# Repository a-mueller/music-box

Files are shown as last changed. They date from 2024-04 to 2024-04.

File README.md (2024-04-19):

# Music Box

A rfid based player I made. It basically scans for RFID takes, and looks for a WAV file on the SD card with that ID, if found it plays it.
The WAV files need to be 22khz, 16bit mono. Audacity is a good tool to convert mp3s.

## Board

The board is simply a pico with and SD card and the I2S chip.

See KiCad files.

### Schematic

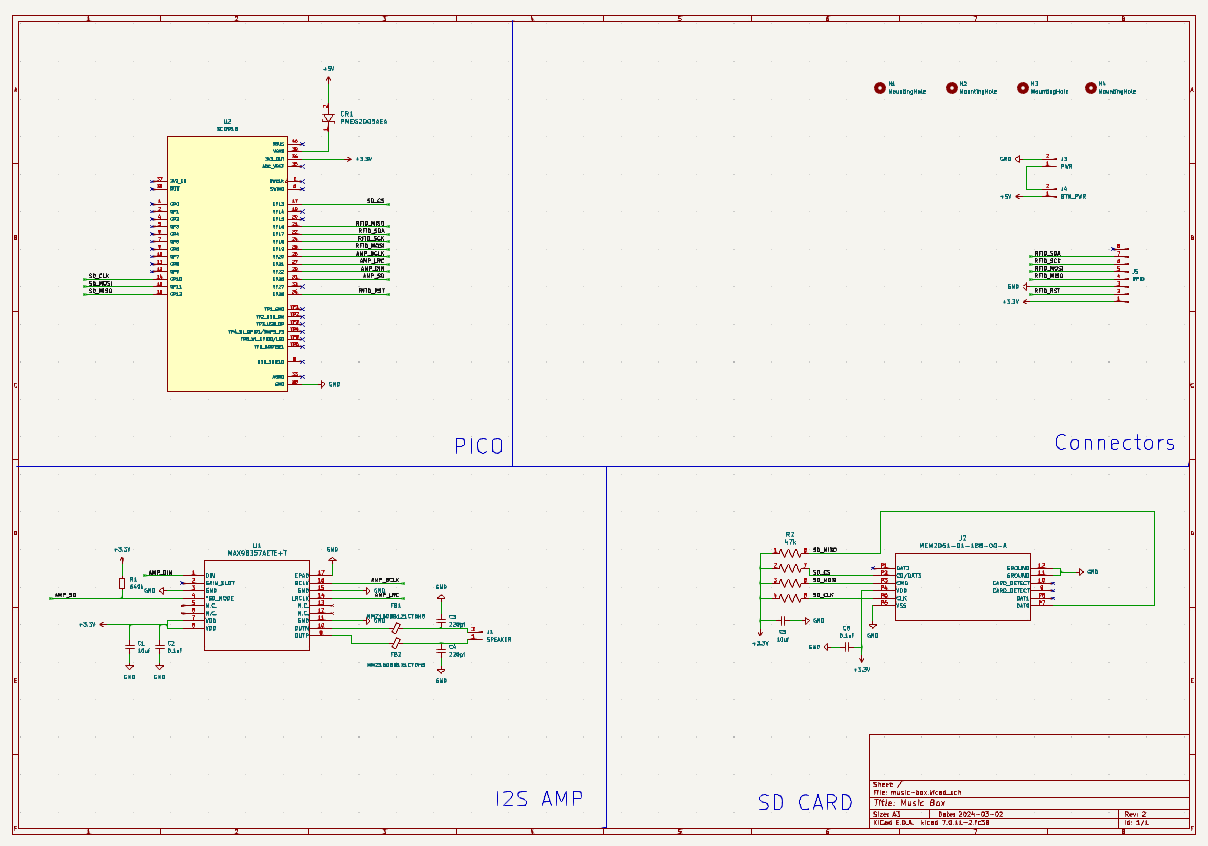
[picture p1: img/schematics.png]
Schematic


### PCB

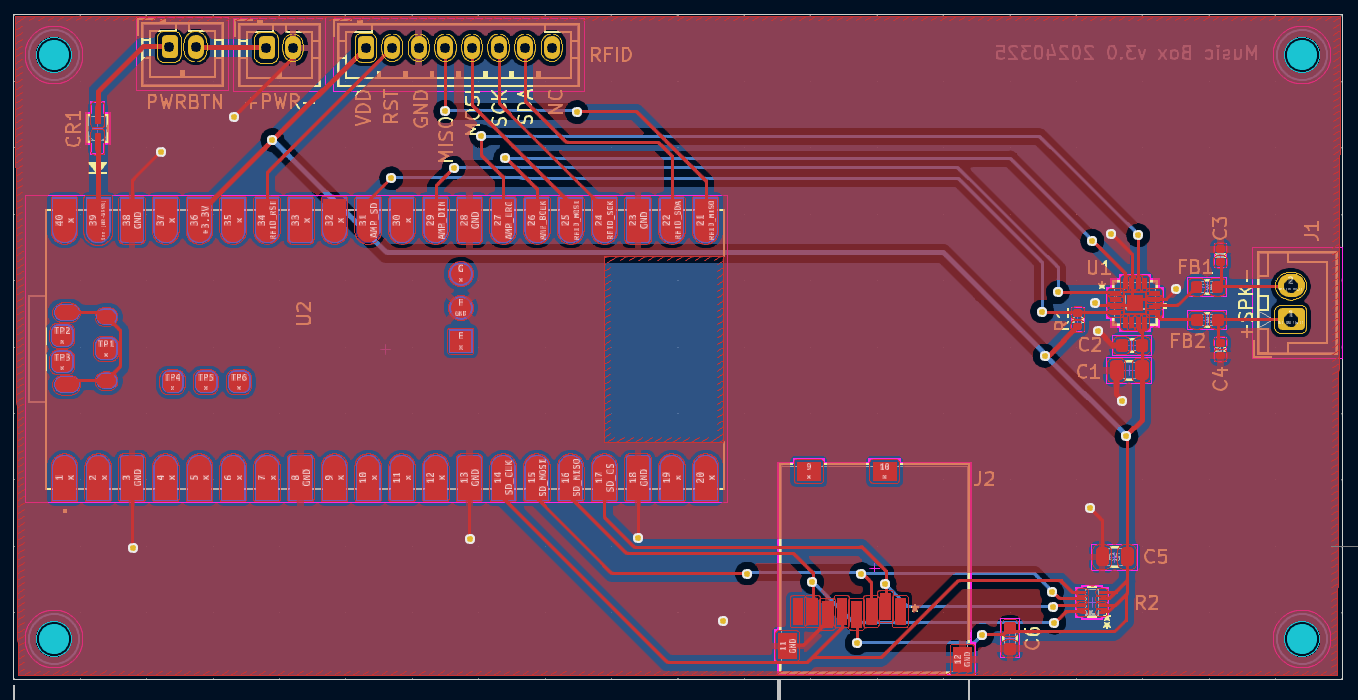
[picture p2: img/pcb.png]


### BOM

<table>
<tr><td>CR1</td><td>PMEG2005AEA</td><td>https://uk.farnell.com/nexperia/pmeg2005aea-115/diode-schottky-sod-323/dp/8737843?st=pmeg2005aea</td></tr>
<tr><td>J2</td><td>GCT MEM2061-01-188-00-A</td><td>https://uk.farnell.com/gct-global-connector-technology/mem2061-01-188-00-a/micro-sd-conn-push-push-8pos-smt/dp/2678544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</td></tr>
<tr><td>C6, C2</td><td>0.1uf, 0603</td><td></td></tr>
<tr><td>C5, C1</td><td>10uf, 0805</td><td></td></tr>
<tr><td>R2</td><td>Array, 4x 47k (EXB-N8V473JX)</td><td>https://uk.farnell.com/panasonic/exbn8v473jx/resistor-ccav-array-0402x4-47k/dp/2060146?st=EXBN8V473JX</td></tr>
<tr><td>R6</td><td>649k, 0402</td><td></td></tr>
<tr><td>U1</td><td>I2S Amp, MAX98357AETE+T</td><td>https://uk.farnell.com/analog-devices/max98357aete-t/audio-power-amp-d-40-to-85deg/dp/2949165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</td></tr>
<tr><td>FB1, FB2</td><td>Ferrite Beads, MMZ1608B121CTDH5</td><td>https://uk.farnell.com/tdk/mmz1608b121ctdh5/ferrite-chip-bead-1608-0-15-ohm/dp/3386884?st=mmz1608b121ctdh5</td></tr>
<tr><td>C4,C3</td><td>220pf, 0402</td><td></td></tr>
<tr><td>J1</td><td>JST, XH 2.5mm</td><td></td></tr>
<tr><td>J4, J3, J5</td><td>JST, PH, 2mm</td><td></td></tr>

</table>

## Software

Flash circuit python (originally I used v9) and copy the lib folder and `code.py` files over. That should be it.

## Case

See FreeCad files in `3dPrinting`, you will need a usbc power board as well to power it (see https://github.com/a-mueller/usbc_power_supply_2)

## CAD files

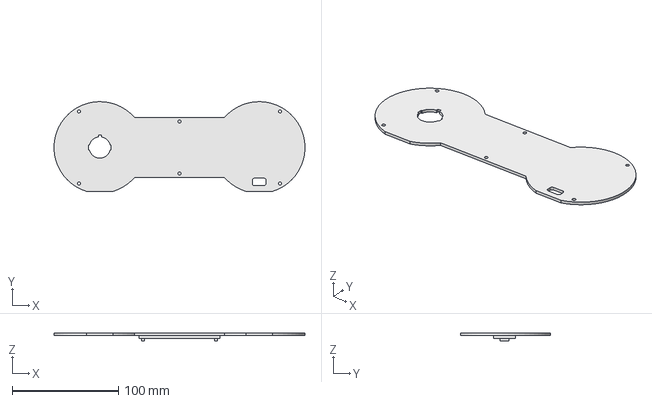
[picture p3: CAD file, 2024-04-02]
3dPrinting/music-box-2.FCStd
236.2 x 84.5 x 7.90 mm

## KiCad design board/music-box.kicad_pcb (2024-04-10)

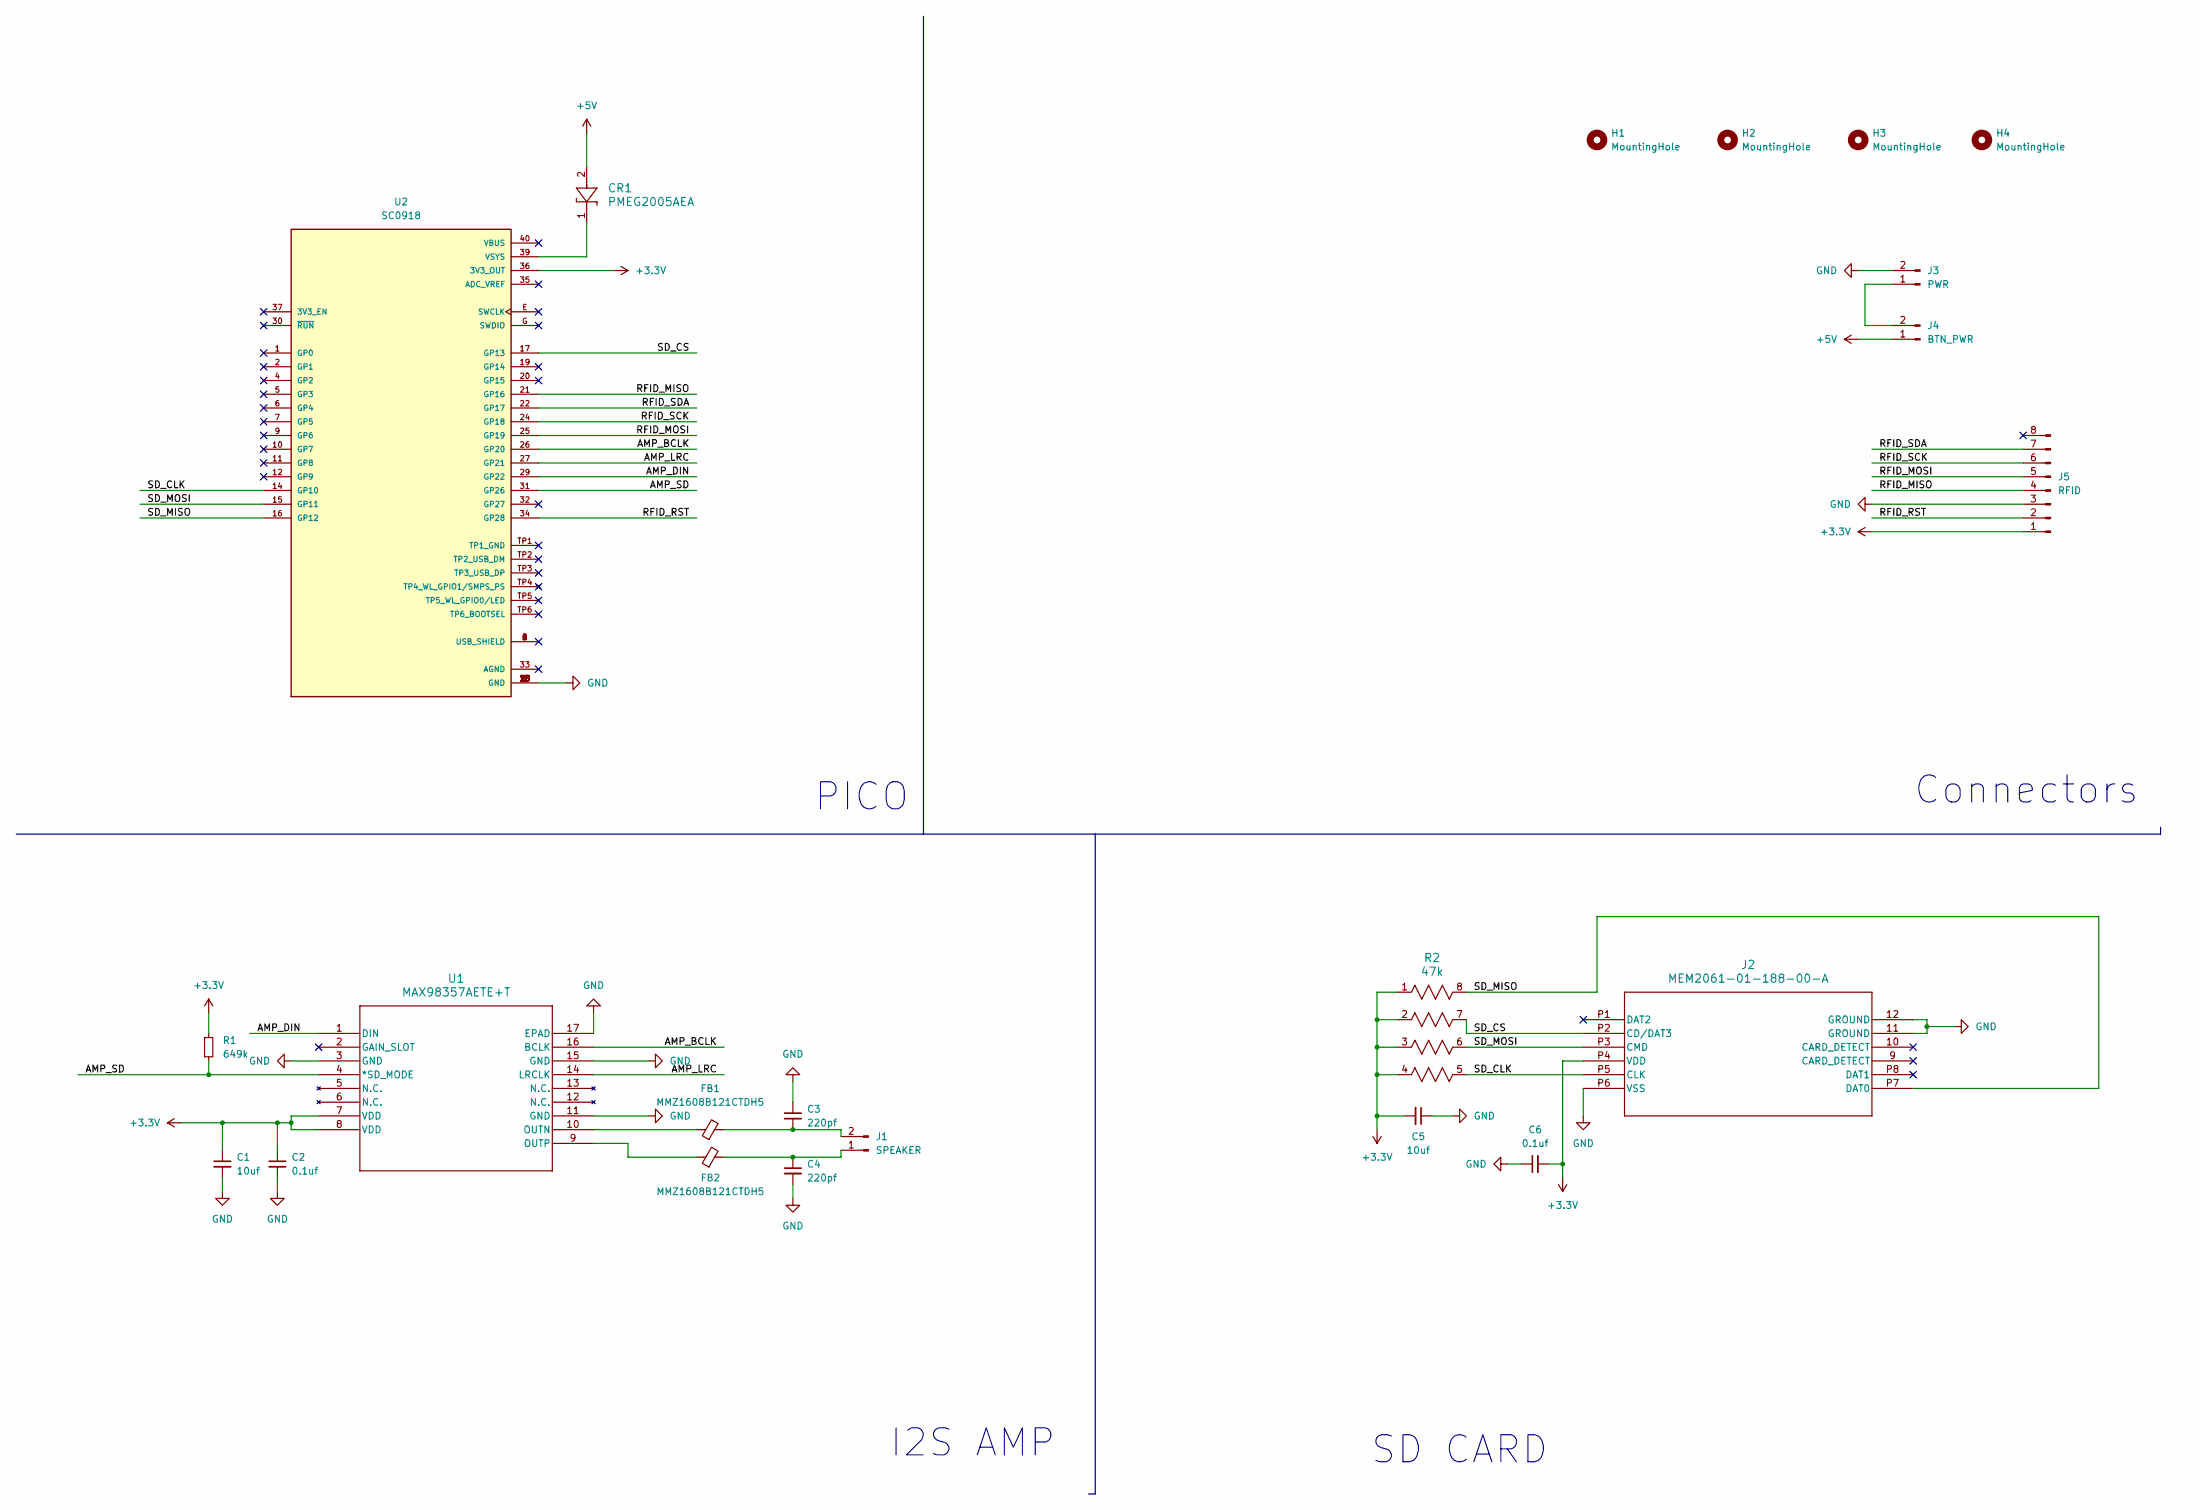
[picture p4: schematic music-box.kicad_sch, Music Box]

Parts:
C1, C5: 10uf; C_0805_2012Metric
C2, C6: 0.1uf; C_0603_1608Metric
C3, C4: 220pf; C_0402_1005Metric
CR1: PMEG2005AEA; SOD323F_NEX
FB1, FB2: MMZ1608B121CTDH5; L_0603_1608Metric
H1, H2, H3, H4: MountingHole; MountingHole_2.2mm_M2_DIN965
J1: SPEAKER; JST_XH_B2B-XH-A_1x02_P2.50mm_Vertical
J2: MEM2061-01-188-00-A; MEM2061-01-188-00-A_GCT
J3: PWR; JST_PH_B2B-PH-K_1x02_P2.00mm_Vertical
J4: BTN_PWR; JST_PH_B2B-PH-K_1x02_P2.00mm_Vertical
J5: RFID; JST_PH_B8B-PH-K_1x08_P2.00mm_Vertical
R1: 649k; R_0402_1005Metric
R2: 47k; EXBN8V_PAN
U1: MAX98357AETE+T; 21-0136I_T1633-4_MXM
U2: SC0918; MODULE_SC0918; PARTREV 2.1

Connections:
+3.3V: C1.1, C2.1, C5.2, C6.2, J2.P4 (VDD), J5.1, R1.1, R2.1, R2.2, R2.3, R2.4, U1.7 (VDD), U1.8 (VDD), U2.36 (3V3_OUT)
+5V: CR1.2, J4.1
/AMP_BCLK: U1.16 (BCLK), U2.26 (GP20)
/AMP_DIN: U1.1 (DIN), U2.29 (GP22)
/AMP_LRC: U1.14 (LRCLK), U2.27 (GP21)
/AMP_SD: R1.2, U1.4 (*SD_MODE), U2.31 (GP26)
/RFID_MISO: J5.4, U2.21 (GP16)
/RFID_MOSI: J5.5, U2.25 (GP19)
/RFID_RST: J5.2, U2.34 (GP28)
/RFID_SCK: J5.6, U2.24 (GP18)
/RFID_SDA: J5.7, U2.22 (GP17)
/SD_CLK: J2.P5 (CLK), R2.5, U2.14 (GP10)
/SD_CS: J2.P2 (CD/DAT3), R2.7, U2.17 (GP13)
/SD_MISO: J2.P7 (DAT0), R2.8, U2.16 (GP12)
/SD_MOSI: J2.P3 (CMD), R2.6, U2.15 (GP11)
GND: C1.2, C2.2, C3.1, C4.2, C5.1, C6.1, J2.11 (GROUND), J2.12 (GROUND), J2.P6 (VSS), J3.2, J5.3, U1.3 (GND), U1.11 (GND), U1.15 (GND), U1.17 (EPAD), U2.3 (GND), U2.8 (GND), U2.13 (GND), U2.18 (GND), U2.23 (GND), U2.28 (GND), U2.38 (GND), U2.F (GND)
unnamed: C4.1, FB2.2, J1.1
unnamed: C3.2, FB1.2, J1.2
unnamed: J3.1, J4.2
unnamed: FB1.1, U1.10 (OUTN)
unnamed: FB2.1, U1.9 (OUTP)
unnamed: CR1.1, U2.39 (VSYS)

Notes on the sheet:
Connectors
I2S AMP
PICO
SD CARD

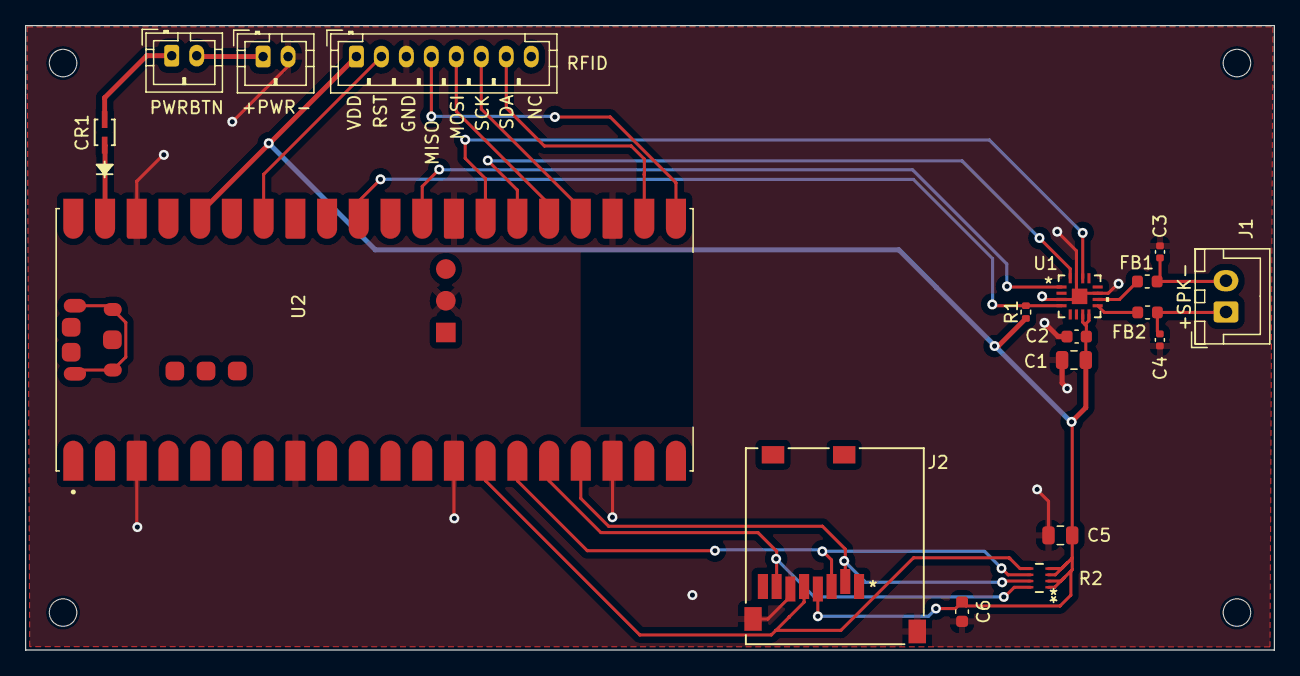
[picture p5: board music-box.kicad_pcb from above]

Board: 2 copper layers, 100.0 x 50.0 mm, 22 parts (0 on the bottom side), 22 nets.

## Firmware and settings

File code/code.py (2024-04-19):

import time
import array
import math
import audiocore
import board
import audiobusio
import busio
import digitalio
import storage
import adafruit_sdcard
import mfrc522
import alarm
import os

print("Running music box")

# SPI for the SD card
spi_sd = busio.SPI(clock = board.GP10, MOSI = board.GP11, MISO = board.GP12) #clock, mosi, miso
# Select pin for the SD card
sd_select = digitalio.DigitalInOut(board.GP13)
# SD card lib
sdcard = adafruit_sdcard.SDCard(spi_sd, sd_select)

while True:
  try:
    # mount the sd card to /sd
    vfs = storage.VfsFat(sdcard)
    storage.mount(vfs, "/sd")
    break
  except:
    print("Error mounting SD card")
    time.sleep(1)

# RFID card reader
spi_rfid = busio.SPI(board.GP18, board.GP19, board.GP16) #clock, mosi, miso
rfid = mfrc522.MFRC522(spi_rfid, board.GP28, board.GP17)


# I2S audio output & amp
amp_power = digitalio.DigitalInOut(board.GP26)
amp_power.switch_to_output()
audio = audiobusio.I2SOut(bit_clock=board.GP20, word_select=board.GP21, data=board.GP22)

# Make sure the amp is powered
amp_power.value = True


while True:
  (status, tag_type) = rfid.request(rfid.REQIDL)
  if status == rfid.OK:
    (stat, raw_uid) = rfid.anticoll()
    if (stat == rfid.OK):
      uid = "0x" + "%02x%02x%02x%02x" % (raw_uid[0], raw_uid[1], raw_uid[2], raw_uid[3])
      path = "/sd/" + "%02x%02x%02x%02x.wav" % (raw_uid[0], raw_uid[1], raw_uid[2], raw_uid[3])
      try:
        os.stat(path)
      except:
        path = "/unknown_card.wav"

      print("Playing path: "+path)

      with open(path, "rb") as wave_file:
        wave = audiocore.WaveFile(wave_file)
        audio.play(wave)
        while (audio.playing and stat == rfid.OK):
          time.sleep(0.5)
          (stat, raw_uid) = rfid.anticoll()

        print("Stopping audio path: "+path)
        audio.stop()
  #
  #   while (stat == rfid.OK):
  #     uid = "0x" + "%02x%02x%02x%02x" % (raw_uid[0], raw_uid[1], raw_uid[2], raw_uid[3])
  #     path = "/sd/" + "%02x%02x%02x%02x.wav" % (raw_uid[0], raw_uid[1], raw_uid[2], raw_uid[3])
  #     print("uuid: "+uid)
  #     time.sleep(1)
  #     (stat, raw_uid) = rfid.anticoll()
  #   print("not ok anticoll")
  # else:
  #   print("not ok requidl")
  time.sleep(1)

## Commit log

2024-04-02 adds board (KiCad)
    [music-box.kicad_pcb, music-box.kicad_sch]
2024-04-02 adds 3dPrinting files and test code
    [music-box-2.FCStd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]
2024-04-10 fixed issue with board (rx / tx swap for the sd card)
    [music-box-B_Cu.gbr, music-box-B_Mask.gbr, music-box-B_Paste.gbr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]
2024-04-23 upgrades board files to kicad 8
    [music-box.kicad_sch]
